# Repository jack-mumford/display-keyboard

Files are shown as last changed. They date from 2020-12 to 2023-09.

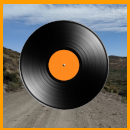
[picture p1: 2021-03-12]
images/generic_cover.png

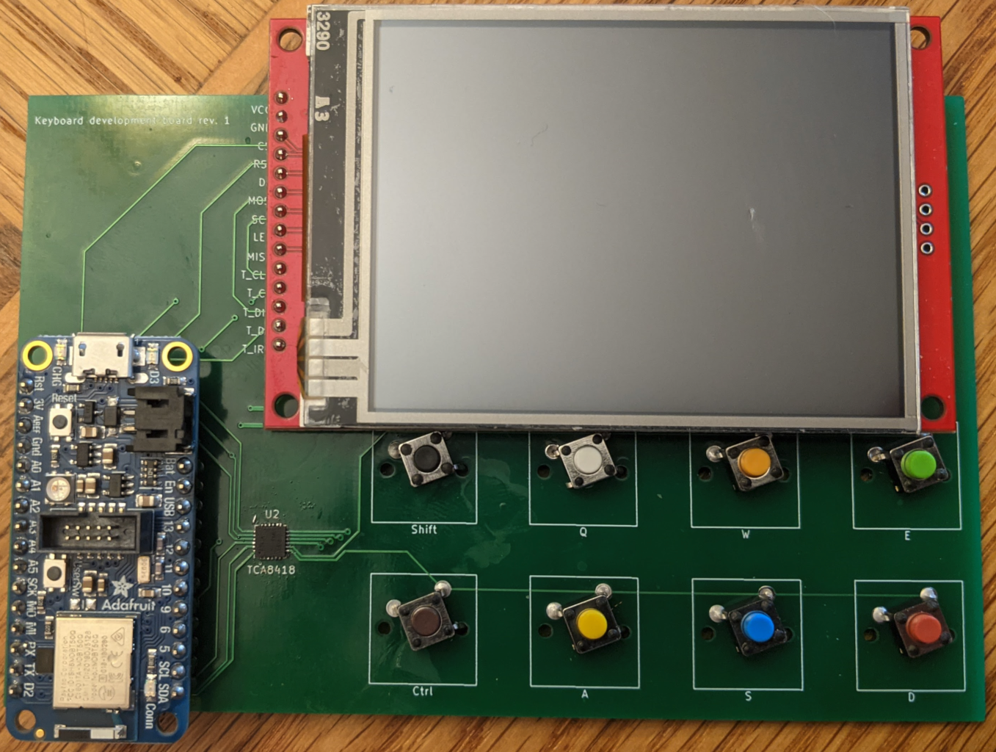
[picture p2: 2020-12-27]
pcb/mainpcb/board.png

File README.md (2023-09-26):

# Display Keyboard

This project is the hardware design and software for a USB keyboard with an
integrated touch display.



Hardware features:

* Mechanical keys.
* [FeatherS2](https://unexpectedmaker.com/shop/feathers2-esp32-s2). This is a
  [ESP32-S2](https://www.espressif.com/sites/default/files/documentation/esp32-s2_datasheet_en.pdf)
  based embedded development board.
* 2.8" LCD capacitive [touch display](https://www.adafruit.com/product/2770).
* 0.91" vertical [OLED display](https://www.aliexpress.com/item/32672229793.html)
  for volume display.
* Volume control knob.

The FeatherS2 conforms to the [Adafruit Feather](https://www.adafruit.com/feather)
requirements, and allows for the possibility of replacing that MCU with another
Feather with little (if any) PCB rework.

## Hardware Design

Design is done in [KiCad](https://kicad.org/). Files are located in
the [pcb](pcb) directory.

## Software Requirements

* [ESP-IDF](https://docs.espressif.com/)
* [VS Code extensions](https://docs.espressif.com/projects/esp-idf/en/latest/esp32/get-started/vscode-setup.html)
  (optional)

## Getting Code

```sh
git clone https://github.com/jack-mumford/display-keyboard.git
cd display-keyboard
./make submodules
```

**Note**: This project makes use of new features (USB) of the ESP32-S2
          and requires ESP-IDF v4.3.

## Building

Do this after opening a new terminal window:

```sh
. $HOME/esp/esp-idf/export.sh
```

Build and flash to the attached ESP32-S2 device as so:

```sh
./make flash
```

Configuration (GPIO pins, etc.) is stored in the sdkconfig.defaults file. This can
be changed using menuconfig as so:

```sh
./make config
```

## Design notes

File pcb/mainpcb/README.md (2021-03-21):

The prototype board is to validate the proper use of the
[LM8330](https://www.ti.com/lit/ds/symlink/lm8330.pdf) keyboard IC.

This is a four layer PCB:

* [Schematic](Schematic.pdf)
* [Layout](Layout.pdf)

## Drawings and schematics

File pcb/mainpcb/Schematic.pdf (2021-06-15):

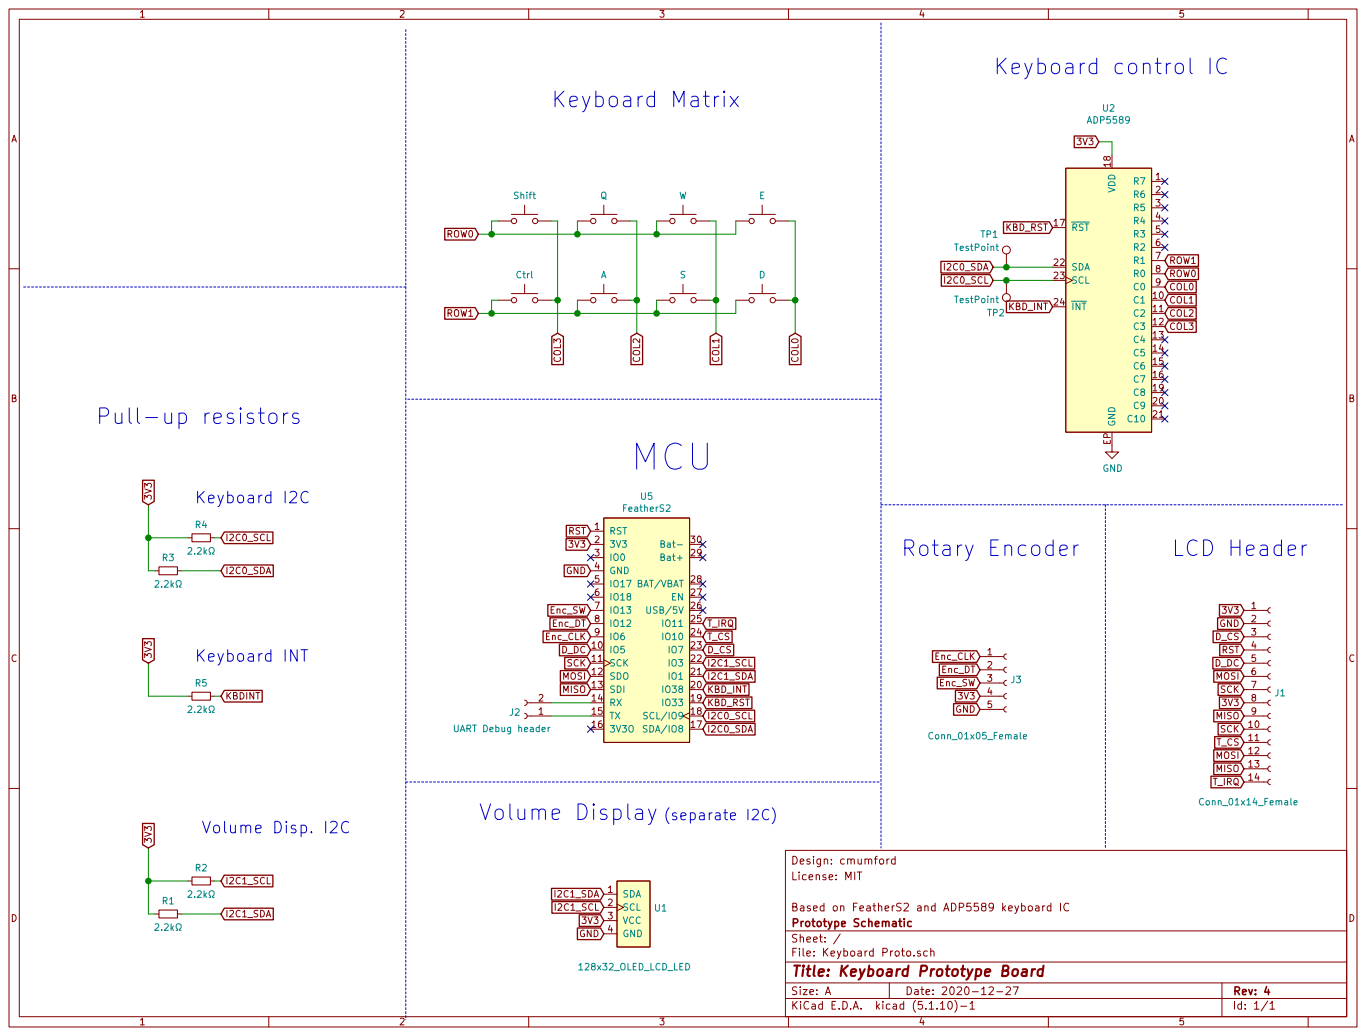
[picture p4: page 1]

Based on FeatherS2 and ADP5589 keyboard IC
File: Keyboard Proto.sch Sheet: / Prototype Schematic

Id: 1/1 Title: Keyboard Prototype Board

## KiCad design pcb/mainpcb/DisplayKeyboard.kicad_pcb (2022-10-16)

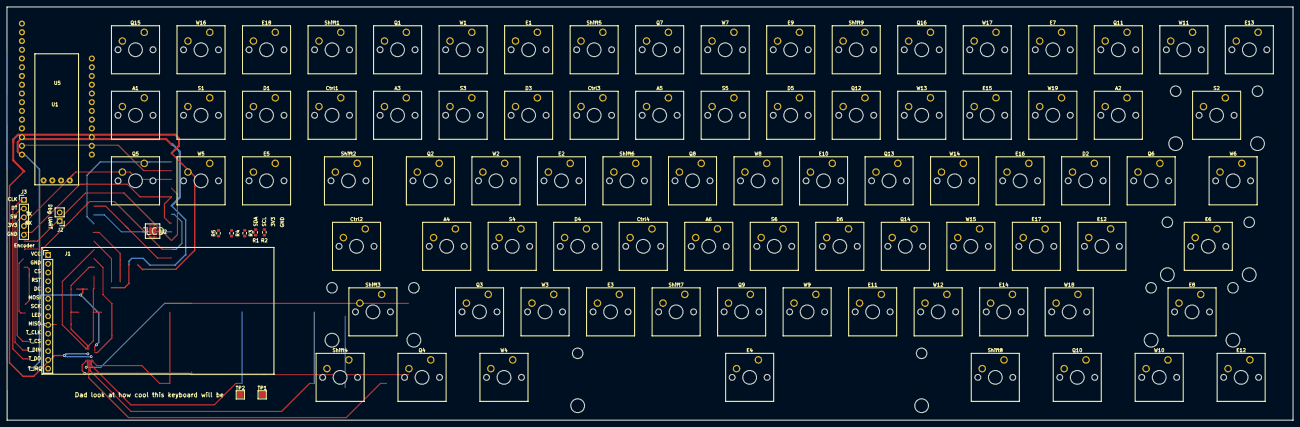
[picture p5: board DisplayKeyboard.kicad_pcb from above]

Board: 2 copper layers, 373.9 x 120.1 mm, 98 parts (0 on the bottom side), 31 nets.

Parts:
A1: Delete/End; SW_Cherry_MX_1.00u_PCB
A2: = +; SW_Cherry_MX_1.00u_PCB
A3: 1 !; SW_Cherry_MX_1.00u_PCB
A4: A; SW_Cherry_MX_1.00u_PCB
A5: 5 %; SW_Cherry_MX_1.00u_PCB
A6: G; SW_Cherry_MX_1.00u_PCB
Ctrl1: `; SW_Cherry_MX_1.00u_PCB
Ctrl2: Caps; SW_Cherry_MX_1.75u_PCB
Ctrl3: 4 $; SW_Cherry_MX_1.00u_PCB
Ctrl4: F; SW_Cherry_MX_1.00u_PCB
D1: Page Down; SW_Cherry_MX_1.00u_PCB
D2: [ {; SW_Cherry_MX_1.00u_PCB
D3: 3 #; SW_Cherry_MX_1.00u_PCB
D4: D; SW_Cherry_MX_1.00u_PCB
D5: 7 &; SW_Cherry_MX_1.00u_PCB
D6: J; SW_Cherry_MX_1.00u_PCB
E1: F3; SW_Cherry_MX_1.00u_PCB
E2: E; SW_Cherry_MX_1.00u_PCB
E3: C; SW_Cherry_MX_1.00u_PCB
E4: Space; SW_Cherry_MX_6.25u_PCB
E5: RIGHT; SW_Cherry_MX_1.00u_PCB
E6: Enter; SW_Cherry_MX_2.25u_PCB
E7: F11; SW_Cherry_MX_1.00u_PCB
E8: Right Shift; SW_Cherry_MX_2.75u_PCB
E9: F7; SW_Cherry_MX_1.00u_PCB
E10: U; SW_Cherry_MX_1.00u_PCB
E11: M; SW_Cherry_MX_1.00u_PCB
E12: Right Control; SW_Cherry_MX_1.25u_PCB
E12#2: " '; SW_Cherry_MX_1.00u_PCB
E13: Num Lock; SW_Cherry_MX_1.00u_PCB
E14: . >; SW_Cherry_MX_1.00u_PCB
E15: 0 ); SW_Cherry_MX_1.00u_PCB
E16: P; SW_Cherry_MX_1.00u_PCB
E17: ; :; SW_Cherry_MX_1.00u_PCB
E18: Page UP; SW_Cherry_MX_1.00u_PCB
J1: Conn_01x14_Female; PinHeader_1x14_P2.54mm_Vertical
J2: UART Debug header; PinHeader_1x02_P2.54mm_Vertical
J3: Conn_01x05_Female; PinHeader_1x05_P2.54mm_Vertical
Q1: F1; SW_Cherry_MX_1.00u_PCB
Q2: Q; SW_Cherry_MX_1.00u_PCB
Q3: Z; SW_Cherry_MX_1.00u_PCB
Q4, Q10: Windows; SW_Cherry_MX_1.25u_PCB
Q5: LEFT; SW_Cherry_MX_1.00u_PCB
Q6: ] }; SW_Cherry_MX_1.00u_PCB
Q7: F5; SW_Cherry_MX_1.00u_PCB
Q8: T; SW_Cherry_MX_1.00u_PCB
Q9: B; SW_Cherry_MX_1.00u_PCB
Q11: F12; SW_Cherry_MX_1.00u_PCB
Q12: 8 *; SW_Cherry_MX_1.00u_PCB
Q13: I; SW_Cherry_MX_1.00u_PCB
Q14: K; SW_Cherry_MX_1.00u_PCB
Q15: Home/Pause; SW_Cherry_MX_1.00u_PCB
Q16: F9; SW_Cherry_MX_1.00u_PCB
R1, R2, R3, R4, R5: 2.2kΩ; R_0603_1608Metric
S1: UP; SW_Cherry_MX_1.00u_PCB
S2: Delete; SW_Cherry_MX_2.00u_PCB
S3: 2 @; SW_Cherry_MX_1.00u_PCB
S4: S; SW_Cherry_MX_1.00u_PCB
S5: 6 ^; SW_Cherry_MX_1.00u_PCB
S6: H; SW_Cherry_MX_1.00u_PCB
Shift1: Escape; SW_Cherry_MX_1.00u_PCB
Shift2: Tab; SW_Cherry_MX_1.50u_PCB
Shift3: Left Shift; SW_Cherry_MX_2.25u_PCB
Shift4: Control; SW_Cherry_MX_1.25u_PCB
Shift5: F4; SW_Cherry_MX_1.00u_PCB
Shift6: R; SW_Cherry_MX_1.00u_PCB
Shift7: V; SW_Cherry_MX_1.00u_PCB
Shift8: Right Alt; SW_Cherry_MX_1.25u_PCB
Shift9: F8; SW_Cherry_MX_1.00u_PCB
TP1, TP2: TestPoint; TestPoint_Pad_2.0x2.0mm
U1: 128x32_OLED_LCD_LED
U2: ADP5589
U5: FeatherS2
W1: F2; SW_Cherry_MX_1.00u_PCB
W2: W; SW_Cherry_MX_1.00u_PCB
W3: X; SW_Cherry_MX_1.00u_PCB
W4: Left Alt; SW_Cherry_MX_1.25u_PCB
W5: DOWN; SW_Cherry_MX_1.00u_PCB
W6: \ |; SW_Cherry_MX_1.50u_PCB
W7: F6; SW_Cherry_MX_1.00u_PCB
W8: Y; SW_Cherry_MX_1.00u_PCB
W9: N; SW_Cherry_MX_1.00u_PCB
W10: FN; SW_Cherry_MX_1.25u_PCB
W11: Print Screen; SW_Cherry_MX_1.00u_PCB
W12: , <; SW_Cherry_MX_1.00u_PCB
W13: 9 (; SW_Cherry_MX_1.00u_PCB
W14: O; SW_Cherry_MX_1.00u_PCB
W15: L; SW_Cherry_MX_1.00u_PCB
W16: Insert/Delete; SW_Cherry_MX_1.00u_PCB
W17: F10; SW_Cherry_MX_1.00u_PCB
W18: / ?; SW_Cherry_MX_1.00u_PCB
W19: - _; SW_Cherry_MX_1.00u_PCB

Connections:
3V3: J1.1, J1.8, J3.4, R1.2, R2.2, R3.2, R4.2, R5.2, U1.3, U2.18, U5.2
/Sheet60C95FD9/COL1: A3.2, A4.2, Q1.2, Q2.2, Q3.2, Q4.2, S1.2, S2.2
/Sheet60C95FD9/COL2: A1.1, A2.1, A5.2, A6.2, Ctrl3.2, Ctrl4.2, D1.1, D1.2, D2.1, D2.2, D3.2, D4.2, E1.2, E2.2, E3.2, E4.1, E4.2, E5.1, E5.2, E6.1, E6.2, E7.1, E7.2, E8.1, E8.2, E12.1, E12#2.1, E13.1, E13.2, E14.2, E18.1, Q4.1, Q5.1, Q5.2, Q6.1, Q6.2, Q7.2, Q8.2, Q9.2, Q10.1, Q10.2, Q11.1, Q12.2, Q13.2, Q14.2, Q15.1, Q15.2, Q16.2, S1.1, S2.1, S3.2, S4.2, S5.2, S6.2, Shift4.1, Shift5.2, Shift6.2, Shift7.2, Shift8.1, Shift8.2, Shift9.2, W1.2, W2.2, W3.2, W4.1, W4.2, W5.1, W5.2, W6.1, W6.2, W7.2, W8.2, W9.2, W10.1, W10.2, W11.1, W12.2, W13.2, W14.2, W15.2, W16.1, W16.2, W19.1
/Sheet60C95FD9/COL7: D5.2, D6.2, E9.2, E10.2, E11.2, E12.2, E12#2.2, Q11.2
/Sheet60C95FD9/COL10: E15.2, E16.2, E17.2, E18.2, W17.2, W18.2, W19.2
/Sheet60C95FD9/ROW0: E1.1, E9.1, Q1.1, Q7.1, Q16.1, Shift1.1, Shift5.1, Shift9.1, W1.1, W7.1, W17.1
/Sheet60C95FD9/ROW1: A3.1, A5.1, Ctrl1.1, Ctrl3.1, D3.1, D5.1, E15.1, Q12.1, S3.1, S5.1, W13.1
/Sheet60C95FD9/ROW2: E2.1, E10.1, E16.1, Q2.1, Q8.1, Q13.1, Shift2.1, Shift6.1, W2.1, W8.1, W14.1
/Sheet60C95FD9/ROW3: A4.1, A6.1, Ctrl2.1, Ctrl4.1, D4.1, D6.1, E17.1, Q14.1, S4.1, S6.1, W15.1
/Sheet60C95FD9/ROW4: E3.1, E11.1, E14.1, Q3.1, Q9.1, Shift3.1, Shift7.1, W3.1, W9.1, W12.1, W18.1
COL0: A1.2, A2.2, Ctrl1.2, Ctrl2.2, Shift1.2, Shift2.2, Shift3.2, Shift4.2, U2.9
D_CS: J1.3, U5.23
D_DC: J1.5, U5.10
Enc_CLK: J3.1, U5.9
Enc_DT: J3.2, U5.8
Enc_SW: J3.3, U5.7
GND: J1.2, J3.5, U1.4, U2.EP, U5.4
I2C0_SCL: R4.1, TP2.1, U2.23, U5.18
I2C0_SDA: R3.1, TP1.1, U2.22, U5.17
I2C1_SCL: R2.1, U1.2, U5.22
I2C1_SDA: R1.1, U1.1, U5.21
KBD_INT: R5.1, U2.24, U5.20
KBD_RST: U2.17, U5.19
MISO: J1.9, J1.13, U5.13
MOSI: J1.6, J1.12, U5.12
unnamed: J2.1, U5.15
unnamed: J2.2, U5.14
RST: J1.4, U5.1
SCK: J1.7, J1.10, U5.11
T_CS: J1.11, U5.24
T_IRQ: J1.14, U5.25

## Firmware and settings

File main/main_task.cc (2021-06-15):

#include "main_task.h"

#define LOG_LOCAL_LEVEL ESP_LOG_DEBUG
#include <esp_log.h>
#include <esp_sntp.h>
#include <i2clib/master.h>
#include <nvs_flash/include/nvs_flash.h>

#include "config_reader.h"
#include "event_ids.h"
#include "gpio_pins.h"
#include "keyboard_simulator_task.h"
#include "keyboard_task.h"
#include "ui_task.h"
#include "usb_device.h"
#include "usb_hid.h"
#include "usb_task.h"
#include "volume_task.h"

namespace {

constexpr char TAG[] = "MainTask";

MainTask* g_main_task;

esp_err_t InitNVRAM() {
  esp_err_t ret = nvs_flash_init();
  if (ret == ESP_ERR_NVS_NO_FREE_PAGES ||
      ret == ESP_ERR_NVS_NEW_VERSION_FOUND) {
    ESP_ERROR_CHECK(nvs_flash_erase());
    ret = nvs_flash_init();
  }
  return ret;
}

// static
void SNTPSyncEventHandler(struct timeval* tv) {
  ESP_LOGD(TAG, "NTP sync complete.");
}

}  // namespace

MainTask::MainTask()
    : led_controller_(kActivityGPIO),
      event_group_(xEventGroupCreate()),
      wifi_(event_group_),
      spotify_(&config_, &https_server_, &wifi_, event_group_) {}

MainTask::~MainTask() {
  if (event_group_)
    vEventGroupDelete(event_group_);
  g_main_task = nullptr;
}

esp_err_t MainTask::SetTimezone() {
  if (config_.time.timezone.empty()) {
    ESP_LOGE(TAG, "No timezone");
    return ESP_FAIL;
  }
  ESP_LOGD(TAG, "Setting timezone: %s", config_.time.timezone.c_str());

  setenv("TZ", config_.time.timezone.c_str(), 1);
  tzset();

  return ESP_OK;
}

// static
esp_err_t MainTask::Start() {
  ESP_LOGD(TAG, "Starting Main task");
  if (g_main_task)
    return ESP_FAIL;

  g_main_task = new MainTask();
  return g_main_task->Initialize();
}

/**
 * Initialize SNTP and get the current time.
 *
 * Call once online.
 */
esp_err_t MainTask::InitializSNTP() {
  if (config_.time.ntp_server.empty()) {
    ESP_LOGE(TAG, "No NTP server");
    return ESP_FAIL;
  }
  ESP_LOGD(TAG, "Initializing SNTP using server: %s",
           config_.time.ntp_server.c_str());
  sntp_setoperatingmode(SNTP_OPMODE_POLL);
  sntp_setservername(0, config_.time.ntp_server.c_str());
  sntp_set_time_sync_notification_cb(SNTPSyncEventHandler);
  sntp_set_sync_mode(SNTP_SYNC_MODE_SMOOTH);
  sntp_init();
  sntp_initialized_ = true;
  return ESP_OK;
}

// static
esp_err_t MainTask::InitializeI2C() {
  // Used for Keyboard.
  constexpr i2c::Master::InitParams i2c_0_config = {
      .i2c_bus = I2C_NUM_0,
      .sda_gpio = kI2C0_SDA_GPIO,
      .scl_gpio = kI2C0_SCL_GPIO,
      .clk_speed = 400'000,
      .sda_pullup_enable = false,
      .scl_pullup_enable = false,
  };
  if (!i2c::Master::Initialize(i2c_0_config)) {
    ESP_LOGE(TAG, "Can't initialize I2C0");
    return ESP_FAIL;
  }

// Initialize if not using tarablessd1306 for volume display.
#ifndef CONFIG_SSD1306_ENABLE_DEFAULT_I2C_INTERFACE
  // Used for volume display.
  constexpr i2c::Master::InitParams i2c_1_config = {
      .i2c_bus = I2C_NUM_1,
      .sda_gpio = kI2C1_SDA_GPIO,
      .scl_gpio = kI2C1_SCL_GPIO,
      .clk_speed = 400'000,
      .sda_pullup_enable = false,
      .scl_pullup_enable = false,
  };
  if (!i2c::Master::Initialize(i2c_1_config)) {
    ESP_LOGE(TAG, "Can't initialize I2C1");
    return ESP_FAIL;
  }
#endif  // CONFIG_SSD1306_ENABLE_DEFAULT_I2C_INTERFACE

  return ESP_OK;
}

esp_err_t MainTask::Initialize() {
  // https://www.freertos.org/FAQMem.html#StackSize
  constexpr uint32_t kStackDepthWords = 3 * 1024;

  esp_err_t err;

  if (!event_group_)
    return ESP_FAIL;

  err = InitNVRAM();
  if (err != ESP_OK)
    return err;

  err = UITask::Start();
  if (err != ESP_OK)
    return err;

  err = InitializeI2C();
  if (err != ESP_OK)
    return err;

  err = esp_event_loop_create_default();
  if (err != ESP_OK)
    return err;

  err = filesystem_.Initialize();
  if (err != ESP_OK)
    return err;

  ConfigReader config_reader;
  err = config_reader.Read(&config_);
  if (err != ESP_OK)
    return err;
  ESP_LOGI(TAG, "Wi-Fi SSID: \"%s\"", config_.wifi.ssid.c_str());

  ESP_ERROR_CHECK_WITHOUT_ABORT(SetTimezone());

  err = led_controller_.Initialize();
  if (err != ESP_OK)
    return err;

  err = USBTask::Start();
  if (err != ESP_OK)
    return err;

  err = KeyboardTask::Start();
  if (err != ESP_OK)
    return err;

#if 0
  // Just for testing.
  KeyboardSimulatorTask::Start();
#endif

  err = VolumeTask::Start();
  if (err != ESP_OK)
    return err;

  err = wifi_.Inititialize();
  if (err != ESP_OK)
    return err;

  err = wifi_.InitiateConnection(config_.wifi.ssid, config_.wifi.key);
  if (err != ESP_OK)
    return err;

  return xTaskCreate(TaskFunc, TAG, kStackDepthWords, this,
                     tskIDLE_PRIORITY + 1, &task_) == pdPASS
             ? ESP_OK
             : ESP_FAIL;
}

// TODO: Clean this up. Make Spotify manage it's state and
// this task is only informed of that state.
void MainTask::UpdateSpotify() {
  if (!online_)
    return;
  if (!spotify_.initialized()) {
    ESP_ERROR_CHECK_WITHOUT_ABORT(spotify_.Initialize());
    std::string auth_start_url = spotify_.GetAuthStartURL();
    ESP_LOGI(TAG, "To login to Spotify navigate to %s", auth_start_url.c_str());
  }

  if (spotify_.initialized()) {
    if (spotify_.HaveAuthorizatonCode()) {
      ESP_LOGD(TAG, "Got authorization code, getting token.");
      ESP_ERROR_CHECK_WITHOUT_ABORT(spotify_.ContinueLogin());
    } else if (spotify_need_access_token_refresh_) {
      spotify_need_access_token_refresh_ = false;
      spotify_.RefreshAccessToken();
    } else if (!started_spotify_currently_playing_ &&
               spotify_.HaveAccessToken()) {
      ESP_LOGD(TAG, "Getting Spotify currently playing info.");
      started_spotify_currently_playing_ = true;
      ESP_ERROR_CHECK_WITHOUT_ABORT(spotify_.GetCurrentlyPlaying());
    }
  }
}

void IRAM_ATTR MainTask::Run() {
  ESP_LOGW(TAG, "In Wi-Fi status task handler.");
  while (true) {
    EventBits_t bits =
        xEventGroupWaitBits(event_group_, EVENT_ALL, /*xClearOnExit=*/pdTRUE,
                            /*xWaitForAllBits=*/pdFALSE, portMAX_DELAY);
    if (bits & EVENT_NETWORK_GOT_IP) {
      ESP_LOGD(TAG, "Wi-Fi is connected.");
      online_ = true;
      UITask::SetWiFiStatus(WiFiStatus::Online);
      if (!sntp_initialized_)
        InitializSNTP();
      UpdateSpotify();
    } else if (bits & EVENT_NETWORK_DISCONNECTED) {
      ESP_LOGW(TAG, "Wi-Fi connection failed.");
      online_ = false;
      UITask::SetWiFiStatus(WiFiStatus::Offline);
      // TODO: Set a timer so that we can retry in a little while.
    }
    if (bits & EVENT_SPOTIFY_GOT_AUTHORIZATION_CODE) {
      ESP_LOGD(TAG, "Got authorization code, getting token.");
      UpdateSpotify();
    }
    if (bits & EVENT_SPOTIFY_ACCESS_TOKEN_GOOD) {
      ESP_LOGD(TAG, "Have access token");
      UpdateSpotify();
    }
    if (bits & EVENT_SPOTIFY_ACCESS_TOKEN_EXPIRE) {
      ESP_LOGD(TAG, "Access token needs refresh");
      UpdateSpotify();
    }
  }
}

// static
void IRAM_ATTR MainTask::TaskFunc(void* arg) {
  static_cast<MainTask*>(arg)->Run();
}

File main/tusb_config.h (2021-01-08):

/*
 * The MIT License (MIT)
 *
 * Copyright (c) 2019 Ha Thach (tinyusb.org)
 *
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
 */

#ifndef _TUSB_CONFIG_H_
#define _TUSB_CONFIG_H_

#ifdef __cplusplus
extern "C" {
#endif

//--------------------------------------------------------------------
// COMMON CONFIGURATION
//--------------------------------------------------------------------

// defined by board.mk
#ifndef CFG_TUSB_MCU
#error CFG_TUSB_MCU must be defined
#endif

// RHPort number used for device can be defined by board.mk, default to port 0
#ifndef BOARD_DEVICE_RHPORT_NUM
#define BOARD_DEVICE_RHPORT_NUM 0
#endif

// RHPort max operational speed can defined by board.mk
// Default to Highspeed for MCU with internal HighSpeed PHY (can be port
// specific), otherwise FullSpeed
#ifndef BOARD_DEVICE_RHPORT_SPEED
#if (CFG_TUSB_MCU == OPT_MCU_LPC18XX || CFG_TUSB_MCU == OPT_MCU_LPC43XX ||   \
     CFG_TUSB_MCU == OPT_MCU_MIMXRT10XX || CFG_TUSB_MCU == OPT_MCU_NUC505 || \
     CFG_TUSB_MCU == OPT_MCU_CXD56)
#define BOARD_DEVICE_RHPORT_SPEED OPT_MODE_HIGH_SPEED
#else
#define BOARD_DEVICE_RHPORT_SPEED OPT_MODE_FULL_SPEED
#endif
#endif

// Device mode with rhport and speed defined by board.mk
#if BOARD_DEVICE_RHPORT_NUM == 0
#define CFG_TUSB_RHPORT0_MODE (OPT_MODE_DEVICE | BOARD_DEVICE_RHPORT_SPEED)
#elif BOARD_DEVICE_RHPORT_NUM == 1
#define CFG_TUSB_RHPORT1_MODE (OPT_MODE_DEVICE | BOARD_DEVICE_RHPORT_SPEED)
#else
#error "Incorrect RHPort configuration"
#endif

// This examples use FreeRTOS
#define CFG_TUSB_OS OPT_OS_FREERTOS

// CFG_TUSB_DEBUG is defined by compiler in DEBUG build
#define CFG_TUSB_DEBUG 0

/* USB DMA on some MCUs can only access a specific SRAM region with restriction
 * on alignment. Tinyusb use follows macros to declare transferring memory so
 * that they can be put into those specific section. e.g
 * - CFG_TUSB_MEM SECTION : __attribute__ (( section(".usb_ram") ))
 * - CFG_TUSB_MEM_ALIGN   : __attribute__ ((aligned(4)))
 */
#ifndef CFG_TUSB_MEM_SECTION
#define CFG_TUSB_MEM_SECTION
#endif

#ifndef CFG_TUSB_MEM_ALIGN
#define CFG_TUSB_MEM_ALIGN __attribute__((aligned(4)))
#endif

//--------------------------------------------------------------------
// DEVICE CONFIGURATION
//--------------------------------------------------------------------

#ifndef CFG_TUD_ENDPOINT0_SIZE
#define CFG_TUD_ENDPOINT0_SIZE 64
#endif

//------------- CLASS -------------//
#define CFG_TUD_HID 1
#define CFG_TUD_CDC 0
#define CFG_TUD_MSC 0
#define CFG_TUD_MIDI 0
#define CFG_TUD_VENDOR 0

// HID buffer size Should be sufficient to hold ID (if any) + Data
#define CFG_TUD_HID_EP_BUFSIZE 16

#ifdef __cplusplus
}
#endif

#endif /* _TUSB_CONFIG_H_ */

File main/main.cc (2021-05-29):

#define LOG_LOCAL_LEVEL ESP_LOG_VERBOSE
#include <esp_log.h>
#include <esp_system.h>
#include <freertos/include/freertos/FreeRTOS.h>
#include <freertos/include/freertos/task.h>
#include <i2clib/master.h>
#include <nvs_flash/include/nvs_flash.h>
#include <sdkconfig.h>

#include "gpio_pins.h"
#include "keyboard.h"
#include "main_task.h"

namespace {

constexpr char TAG[] = "App";

#if (BOARD_FEATHERS2 == 0)
void WaitForDebugMonitor() {
  // Poor man's way of waiting till the monitor has connected.
  const TickType_t kStartupDelay = 1000 / portTICK_PERIOD_MS;
  ESP_LOGI(TAG, "Waiting for debug monitor connection");
  vTaskDelay(kStartupDelay);
}
#endif  // BOARD_FEATHERS2

void LogHardwareInfo() {
  esp_chip_info_t chip_info;
  esp_chip_info(&chip_info);
  ESP_LOGI(TAG, "This is %s chip with %d CPU core(s), WiFi%s%s.",
           CONFIG_IDF_TARGET, chip_info.cores,
           (chip_info.features & CHIP_FEATURE_BT) ? "/BT" : "",
           (chip_info.features & CHIP_FEATURE_BLE) ? "/BLE" : "");

  ESP_LOGI(TAG, "Silicon revision %u.", chip_info.revision);

  ESP_LOGI(
      TAG, "%zu MB %s flash", spi_flash_get_chip_size() / (1024 * 1024),
      (chip_info.features & CHIP_FEATURE_EMB_FLASH) ? "embedded" : "external");

  ESP_LOGI(TAG, "Minimum free heap size: %u bytes.",
           esp_get_minimum_free_heap_size());
}

}  // namespace

extern "C" void app_main(void) {
#if (BOARD_FEATHERS2 == 0)
  // The serial UART is used for Feather S2 debugging (which is always setup)
  // so no need to wait.
  WaitForDebugMonitor();
#endif

  ESP_LOGI(TAG, "Keyboard app!");
  LogHardwareInfo();

  ESP_ERROR_CHECK(MainTask::Start());
}

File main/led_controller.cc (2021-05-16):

/**
 * @file
 *
 * @license
 * THE SOFTWARE IS PROVIDED "AS IS", WITHOUT WARRANTY OF ANY KIND, EXPRESS OR
 * IMPLIED, INCLUDING BUT NOT LIMITED TO THE WARRANTIES OF MERCHANTABILITY,
 * FITNESS FOR A PARTICULAR PURPOSE AND NONINFRINGEMENT. IN NO EVENT SHALL THE
 * AUTHORS OR COPYRIGHT HOLDERS BE LIABLE FOR ANY CLAIM, DAMAGES OR OTHER
 * LIABILITY, WHETHER IN AN ACTION OF CONTRACT, TORT OR OTHERWISE, ARISING
 * FROM, OUT OF OR IN CONNECTION WITH THE SOFTWARE OR THE USE OR OTHER
 * DEALINGS IN THE SOFTWARE.
 */

#include "led_controller.h"

#define LOG_LOCAL_LEVEL ESP_LOG_VERBOSE
#include <driver/gpio.h>
#include <esp_idf_version.h>
#include <esp_timer.h>

#include "gpio_pins.h"

namespace {

constexpr char TAG[] = "LED";
constexpr uint64_t kLEDOffDelayUsec = 50 * 1000;
LEDController* g_led_controller;  // For testing.

}  // namespace

LEDController::LEDController(gpio_num_t activity_gpio)
    : activity_gpio_(activity_gpio),
      led_off_timer_(nullptr),
      rgbled_(GPIO_NUM_45, GPIO_NUM_40, HSPI_HOST) {
  g_led_controller = this;
}

LEDController::~LEDController() {
  esp_timer_stop(led_off_timer_);
  gpio_set_level(activity_gpio_, 0);
  g_led_controller = nullptr;
}

// static:
void IRAM_ATTR LEDController::ActivityTimerCb(void* param) {
  gpio_set_level(static_cast<LEDController*>(param)->activity_gpio_, 0);
}

// static:
LEDController* LEDController::GetForTesting() {
  return g_led_controller;
}

esp_err_t LEDController::Initialize() {
  esp_err_t err;

  err = rgbled_.Initialize();
  ESP_ERROR_CHECK_WITHOUT_ABORT(err);
  if (err == ESP_OK) {
    ESP_ERROR_CHECK_WITHOUT_ABORT(rgbled_.Set(APA102::Color(0, 255, 0)));
  }

#if (BOARD_FEATHERS2 == 1)
  const gpio_config_t config = {
      .pin_bit_mask = (1ULL << activity_gpio_),
      .mode = GPIO_MODE_OUTPUT,
      .pull_up_en = GPIO_PULLUP_DISABLE,
      .pull_down_en = GPIO_PULLDOWN_DISABLE,
      .intr_type = GPIO_INTR_DISABLE,
  };
  err = gpio_config(&config);
  if (err != ESP_OK)
    return err;
#endif
  err = gpio_set_level(activity_gpio_, 0);
  if (err != ESP_OK)
    return err;
  return CreateActivityTimer();
}

esp_err_t LEDController::CreateActivityTimer() {
  const esp_timer_create_args_t timer_args = {
    .callback = ActivityTimerCb,
    .arg = this,
    .dispatch_method = ESP_TIMER_TASK,
    .name = "ActivityTimer",
#if ESP_IDF_VERSION >= ESP_IDF_VERSION_VAL(4, 3, 0)
    .skip_unhandled_events = true,
#endif
  };
  return esp_timer_create(&timer_args, &led_off_timer_);
}

void LEDController::FlashActivityLED() {
  esp_timer_stop(led_off_timer_);
  gpio_set_level(activity_gpio_, 1);
  esp_timer_start_once(led_off_timer_, kLEDOffDelayUsec);
}

void LEDController::SetRGBLED(uint8_t red,
                              uint8_t green,
                              uint8_t blue,
                              uint8_t intensity) {
  // APA102 intensity is a 5-bit value (0..31) - hence the shift.
  ESP_ERROR_CHECK_WITHOUT_ABORT(
      rgbled_.Set(APA102::Color(red, green, blue, intensity >> 3)));
}

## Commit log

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2020-12-11 Upgraded lv_port_esp32 to master w/ESP32-S2 build fix.
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2020-12-12 Loading app config data from SPIFFS filesystem.
    config file is a *.INI file.
    [partitions_keyboard.csv]
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2020-12-13 First prototype board.
    Prototype board rev 1.
    This board uses the [Adafruit Feather nRF52840 Express](https://www.adafruit.com/product/4062)
    which supports USB and Bluetooth, but not Wi-Fi. This is mostly for
    validating the use of the TCA8418 keyboard chip.
    [Keyboard Proto.kicad_pcb, Keyboard Proto.sch]
2020-12-13 Fixed task WDT firing.
    ets_delay_us() is non-yielding and causes the WDT to fire.
    Waiting at least one tick solves this.
    [main.cc]
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2020-12-19 Revert "ESP monitor baud 115200 → 230400."
    This reverts commit 202b55601eef3dfdd372871715187783984b3e7b.
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2020-12-20 Set proto board rev 1 metadata.
    [Keyboard Proto.sch]
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2020-12-22 Added i2clib and Keyboard class.
    Not talking to keyboard yet - just empty class.
    The i2clib cmake configuration isn't correct yet, so its source
    files are specfied in main/CMakeLists.txt.
    [keyboard.cc]
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2020-12-24 Offset storage partition.
    Starting at 2M instead of 1M. Allows space for debug build.
    [partitions_keyboard.csv]
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2020-12-27 proto r2: Prototype board rev2.
    [Keyboard Proto.kicad_pcb, Keyboard Proto.sch]
2020-12-27 proto r2: Changed board metadata.
    [Keyboard Proto.sch]
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2020-12-27 proto r2: Now using LM8330 Keyboard IC.
    Supports 120 keys instead of only 80.
    [Keyboard Proto.sch]
2020-12-27 proto r2: New 1.8V circuitry for LM8330 keyboard IC.
    [Keyboard Proto.sch]
2020-12-27 proto r2: Specified footprints for passives.
    [Keyboard Proto.sch]
2020-12-27 proto r2: Switched to a 4 layer board.
    This is required to use the LM8330 IC which has a FBGA with 0.25 mm
    pad diameter. The 1/2 layer boards have a minimum size of 0.4 mm.
    [Keyboard Proto.kicad_pcb]
2020-12-27 proto r2: Board setup for JLCPCB capacities.
    Some settings as per https://jlcpcb.com/capabilities/Capabilities.
    * Trace clearance: 0.09mm
    * Trace min width: 0.09mm
    * Via min size: 0.45mm
    * Via min drill size: 0.2mm
    * Clearance: 0.127mm
    Note: For 1oz. copper 4/6 layer boards can do 0.09mm, but 1/2 layer
    boards can only go down to 0.127mm.
    [Keyboard Proto.kicad_pcb]
2020-12-27 proto r2: Added a 0.127mm and 0.09mm trace width.
    [Keyboard Proto.kicad_pcb]
2020-12-27 proto r2: Imported current netlist to layout.
    [Keyboard Proto.kicad_pcb]
2020-12-27 proto r2: Changed DRC trace clearance: 0.09 => 0.029
    [Keyboard Proto.kicad_pcb]
2020-12-27 proto r2: Spread out the new ICs, but no routing yet.
    [Keyboard Proto.kicad_pcb]
2020-12-27 proto r2: board cleanup and simple layout (no routing).
    [Keyboard Proto.kicad_pcb]
2020-12-27 proto r2: imported netlist. No real changes.
    [Keyboard Proto.kicad_pcb]
2020-12-27 proto r2: Added debugger UART pin header.
    [Keyboard Proto.kicad_pcb, Keyboard Proto.sch]
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2020-12-27 proto r2: Updated nRF52840 footprint from library.
    [Keyboard Proto.kicad_pcb]
2020-12-28 proto r2: Added rotary encoder + silkscreen text.
    [Keyboard Proto.kicad_pcb, Keyboard Proto.sch]
2020-12-28 proto r2: Replaced nRF52840 with FeatherS2.
    [Keyboard Proto.sch]
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2020-12-28 proto r2: Added footprint for 0.91" OLED display.
    [Keyboard Proto.kicad_pcb]
2020-12-28 proto r2: Added 0.91" OLED to layout.
    [Keyboard Proto.kicad_pcb, Keyboard Proto.sch]
2021-01-01 proto r2: Corrected FeatherS2 pin numbers.
2021-01-01 Layed out. Pins on FeatherS2 are incorrect.
    [Keyboard Proto.kicad_pcb, Keyboard Proto.sch]
2021-01-01 proto r2: Connecting the DC display pin.
    [Keyboard Proto.sch]
2021-01-01 proto r2: Swapped SDI/SDO.
    SDO/IO35 = MOSI
    SDI/IO37 = MISO
    [Keyboard Proto.sch]
2021-01-02 Some work on keyboard (interrupt not working).
    [keyboard.cc, main.cc]
2021-01-02 Reading ESP console config from sdkconfig.
    Knowing now the app us built, and which device it will be
    outputting console log messages, now being used to select
    the correct device.
    [make.py]
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2021-01-07 LM8330: Set correct I2C slave address.
    [keyboard.cc]
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2021-01-08 make.py: Fixed list/scalar bug.
    [make.py]
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2021-01-08 TCA8418: Fixed overflowing keyboard buffer.
    [keyboard.cc]
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2021-01-10 sdkconfig: Corrected default SPI GPIO pins.
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2021-01-10 make.py: Tolerating missing sdkconfig file.
    [make.py]
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2021-01-25 Switched LM8330 to BGA0016 footprint.
    [Keyboard Proto.sch]
2021-01-26 PCB changes for LM8330 breakout.
    [Keyboard Proto.kicad_pcb]
2021-01-26 Corrected Feather S2 symbol.
    Schematic was using the (out of date) backup symbol.
    [Keyboard Proto.kicad_pcb, Keyboard Proto.sch]
2021-01-26 Relayout most of PCB for Feather S2 symbol fix.
    [Keyboard Proto.kicad_pcb]
2021-01-27 proto r2: Relayout complete.
    [Keyboard Proto.kicad_pcb]
2021-01-27 proto r2: Gnd → GND
    [Keyboard Proto.kicad_pcb, Keyboard Proto.sch]
2021-01-27 proto r2: Tweaked silkscreen and removed unneeded vias.
    [Keyboard Proto.kicad_pcb]
2021-01-27 Moved MISO/MOSI traces a little further apart.
    [Keyboard Proto.kicad_pcb]
2021-02-07 Added dot for LSF0204DPWR pin 1.
    [Keyboard Proto.kicad_pcb]
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2021-02-11 Using I2C bus 1 for Volume display.
    The SSD1306 doesn't currently support landscape **and**
    lvgl_esp32_drivers requires that all screens have the same
    orientation. It draws something on screen, but it's a bit
    corrupt at present.
2021-02-13 Ignoring KiCad in .editorconfig.
    KiCad doesn't add a trailing LF to the file.
    Also, skipping C++ indent. Clang-format produces a format that
    .editorconfig finds problematic.
2021-02-13 Added missing quote in make.py.
    [make.py]
2021-02-13 Start of canvas code.
    Appears to be a LVGL bug. Need to debug.
    [volume_display.cc]
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2021-02-20 Fixed a few formatting strings.
    [main.cc]
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2021-02-21 proto r2: Connected LSF0204D EN pin to GND.
    The LSF0204D's EN pin should be pulled low to disable. The
    design was correct for the "non-D" version of the chip.
    [Keyboard Proto.kicad_pcb, Keyboard Proto.sch]
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2021-02-21 Added (crashing) canvas rendering of volume widget.
    [volume_display.cc]
2021-02-24 Added 0.1μF Cap to LM8330 VCC.
    [Keyboard Proto.kicad_pcb, Keyboard Proto.sch]
2021-02-25 Changed level-shifter resistors to 226Ω.
    [Keyboard Proto.sch]
2021-02-26 Switched to tarablessd1306 for volume widget.
    LVGL's multi-display support doesn't work. Using separate
    drawing library for the volume display.
    [main_task.cc, volume_display.cc]
2021-02-27 Inverted volume display and contrast test.
    [volume_display.cc]
2021-02-27 copy of prototype 2
    [Keyboard Proto.kicad_pcb, Keyboard Proto.sch]
2021-02-28 Renamed all Keyboard Proto files to Display Keyboard
    [DisplayKeyboard.kicad_pcb, DisplayKeyboard.sch]
2021-02-28 Fixed a few dangling references to proto2.
    [DisplayKeyboard.sch]
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2021-03-06 Setting custom display buffer size for LVGL TFT to 8192.
    LVGL was causing the device to hand, and for the WDT to
    eventually reset the app. My working theory is that
    LVGL was exhausting the internal heap which it allocates
    for DMA for SPI transfers.
2021-03-06 LM8330: Designated RESETN pin as active low.
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2021-03-07 New Keyboard Matrix Schematic
    [NewKeyboardMatrix.sch]
2021-03-08 Added All Keys to New Keyboard Matrix
    [DisplayKeyboard.sch]
2021-03-08 Added keys and saved properly
    [DisplayKeyboard.sch, NewKeyboardMatrix.sch]
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2021-03-14 Switched to cmumford/TJpgDec.
    The authoritative [TJpgDec](http://elm-chan.org/fsw/tjpgd/00index.html)
    library, which is included unchanged in LVGL's https://github.com/lvgl/lv_lib_split_jpg,
    has memory bugs. Switching to cmumford/TJpgDec, which has some bug fixes
    in these areas, and more suitable for decoding JPEG's downloaded
    from the Internet.
2021-03-20 LM8330: Made RESETN pin active low.
2021-03-21 Using 10-bit keyboard I2C address (not working).
    [keyboard.cc]
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2021-03-24 proto3: Swapped 3.3V/1.8V on level shifter.
    [Keyboard Proto.sch]
2021-03-24 proto3: Relayout for 2-layer.
    [Keyboard Proto.kicad_pcb, Keyboard Proto.sch]
2021-03-24 proto3: Converted from 4 to 2 layers.
    [Keyboard Proto.kicad_pcb]
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2021-03-27 APA102: It is more or less working.
    Outstanding issues:
    1. The RGB pixel values are supposed to be 8-bit values, but
    needed to scale down to 5-bit values to prevent wrapping
    values.
    2. Intensity is not yet correct.
    [apa102.cc, led_controller.cc]
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2021-03-27 Using the TinyUSB that comes with ESP-IDF.
    Switching from this projects TinyUSB library, to the one that is
    included as part of ESP-IDF. Doing this to avoid compiler warnings
    and to (hopefully) increase the likelihood of using a TinyUSB
    version compatible with ESP-IDF.
    At time of the switch am using esp-idf @ 1067b28707e527f177752741e3aa08b5dc64a4d7
    (dated Mar 15, 2021). This switches this project from tinyusb
    @ 42681edaf31ad18fbab6a8b9d581092ae16d841d (Mar 20, 2021)
    to tinyusb @ 334e95fac52a607150157ae5199a19e11f843982 (Jan 8, 2021).
    This switch does not include using the ESP-IDF TinyUSB task, or
    any other ESP-IDF TinyUSB related features.
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2021-03-28 New Version of Main PCB
    [Keyboard Proto.kicad_pcb, Keyboard Proto.sch]
2021-03-28 Copied Keys from old pcb to New PCB
    [Keyboard Proto.sch, NewKeyboardMatrix.sch]
2021-03-28 Imported Pins from Sub Sheet to Main Schematic
    [Keyboard Proto.sch]
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2021-03-28 No More kEyboard proto
    [DisplayKeyboard.sch]
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2021-04-04 Set keyboard RESETN pin to GPIO33.
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2021-04-04 Experimenting with resetting LM8330 at startup.
    [keyboard.cc]
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2021-04-09 Prototype board for ADP5589 keyboard IC.
    [Keyboard Proto.kicad_pcb, Keyboard Proto.sch]
2021-04-09 Modified schematic for ADP5589.
    [Keyboard Proto.sch]
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2021-05-09 Updated ADP5589 footprint.
    Also, first save with KiCAD 5.1.10.
    [Keyboard Proto-B_Cu.gbr, Keyboard Proto-B_Mask.gbr, Keyboard Proto-B_Paste.gbr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]
2021-05-16 Fixed typo: Initlialize => Initialize.
    [apa102.cc, led_controller.cc]
2021-05-16 Fixed pin init 32-bit wrap bug.
    [apa102.cc, led_controller.cc]
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2021-05-30 Corrected hard-coded keyboard key mapping.
    [keyboard.cc]
2021-05-30 Keyboard: Fixed event count check.
    [keyboard.cc]
2021-05-31 keyboard: receiving events.
    Receiving and logging keyboard events. They don't have the correct
    values yet, but making progress.
    [keyboard.cc, keyboard_task.cc]
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2021-06-11 ADP5589: Fixed CoreFrequency constants: MHz → kHz.
    [keyboard.cc]
2021-06-11 Fixed ADP5589 register IO.
    Was incorrectly relying on bitfields being in a specific
    order which was bad practice.
    [keyboard.cc, keyboard_task.cc]
2021-06-11 portYIELD_FROM_ISR correctly for ESP-IDF 4.3.
    [keyboard_task.cc]
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2021-06-12 Fix INT_STATUS register reading.
    [keyboard.cc]
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2021-06-14 proto: added ADP5589 reset pin to IO33.
    [Keyboard Proto.kicad_pcb, Keyboard Proto.sch]
2021-06-15 proto: KBDINT → KBD_INT.
    [Keyboard Proto.kicad_pcb, Keyboard Proto.sch]
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2021-06-15 Filling key_states_ when resetting.
    [keyboard.cc]
2021-06-15 Failing if unable to initialize keyboard.
    [main_task.cc]
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2021-07-13 Fixed kbdlib URL: git@github.com:cmumford/kbdlib.git → https://github.com/cmumford/kbdlib.git.
2021-07-23 Updated schematic/board layout metadata.
    Attributed design to Chris & Jack Mumford.
    [DisplayKeyboard.kicad_pcb, DisplayKeyboard.sch]
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2022-10-16 Added diodes and created labels for 11x8 keyboard layout
    [DisplayKeyboard.kicad_sch, KeyboardsKeys.kicad_sch]
